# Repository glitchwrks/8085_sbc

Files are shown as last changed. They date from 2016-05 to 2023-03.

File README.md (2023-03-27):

# Glitch Works 8085 SBC

This repository contains the recovered EAGLE projects for the various PC boards designed as part of the Glitch Works 8085 SBC projects. These designs have been manufactured and tested and generally found to be functional; however, no warranty is made as to their fitness for any purpose. Please see the [LICENSE](https://github.com/glitchwrks/8085_sbc/blob/master/LICENSE) file for more information.

If you are interested in obtaining a bare circuit board, kit, or assembled board, please contact us through GitHub or [the Glitch Works contact form](https://services.theglitchworks.net/ng/messages/new). There's a chance we'll already have a bare board on hand, since later boards were ordered through [OSH Park](https://oshpark.com/) and resulted in three boards.

If you decide to produce any of these designs, or assemble a board from the provided schematics, please let us know through GitHub or [the Glitch Works contact form](https://services.theglitchworks.net/ng/messages/new).

### 8085 SBC rev 1

This is the original PC board produced from the "mess of wires" that started my exploration into the 8085 CPU! You can read more about the board's evolution and design [here](http://users.glitchwrks.com/~glitch/2010/09/02/8085-sbc). This board was meant to be the CPU board in a stack of boards, and contains 8K EPROM, 8K static RAM, an 8085, and associated clock generation and memory decode circuitry. You can flash a LED on the SOD pin with nothing more than this basic hardware.

### 8085 SBC rev 2

An extension of the rev 1 design, this board incorporates more RAM and ROM, mounting holes, and a few other features. Read about the board [here](http://users.glitchwrks.com/~glitch/2011/10/29/sbc-rev-2).

[AN0001 describes ROM jumpers](https://github.com/glitchwrks/8085_sbc/blob/master/8085_sbc_rev2/an0001_jumpers.txt) for socket IC3.

### I/O Board

This board contains a Zilog SCC (two channel USART) and Intel 8255 PPI to provide two serial ports and 24 bits of parallel I/O. It stacks on top of the 8085 SBC board, PC-104 style. Read about design and testing [here](http://users.glitchwrks.com/~glitch/2017/04/24/8085-io-board). I wrote a [ROM monitor](https://github.com/glitchwrks/gwmon-80) that works with this board. This was on display at [HOPE Number Nine](http://hope.net/) with the vintage computer guys.

There's an [ECO for old etches](https://github.com/glitchwrks/8085_sbc/blob/master/io_board/eco0007.txt) that is relevant if you got one of these boards from us before 2023. It corrects a routing error w.r.t. the 8255 PPI reset signal. See the linked writeup above for a picture documenting the fix.

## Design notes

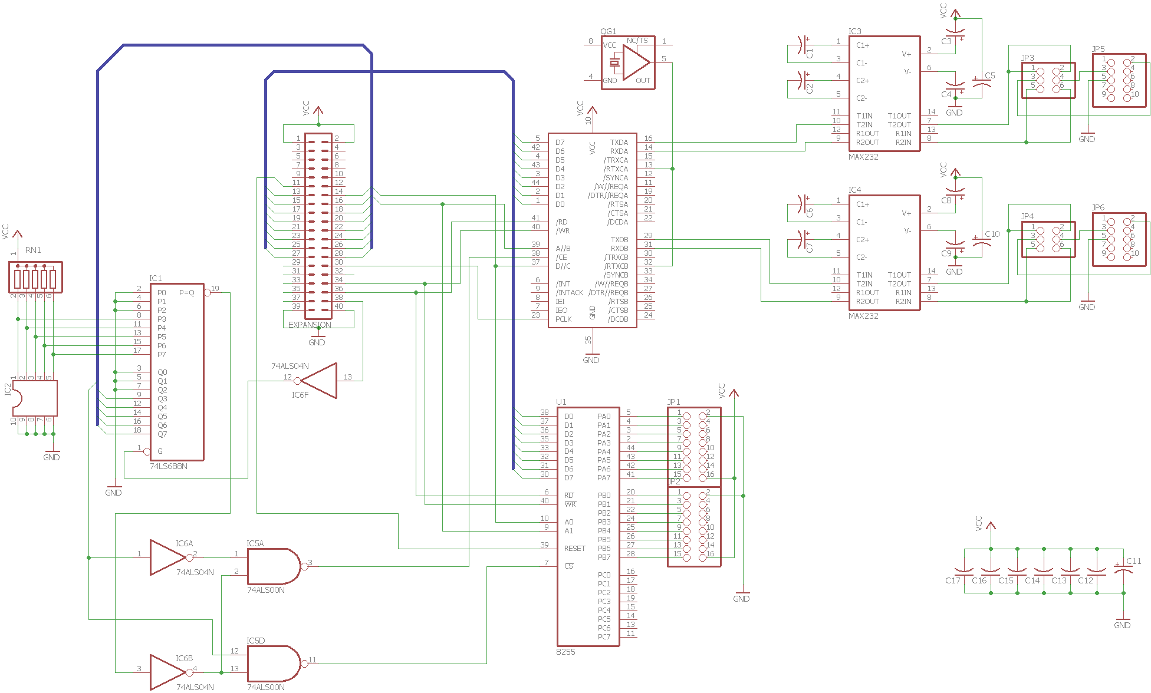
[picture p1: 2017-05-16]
io_board/schematic.png

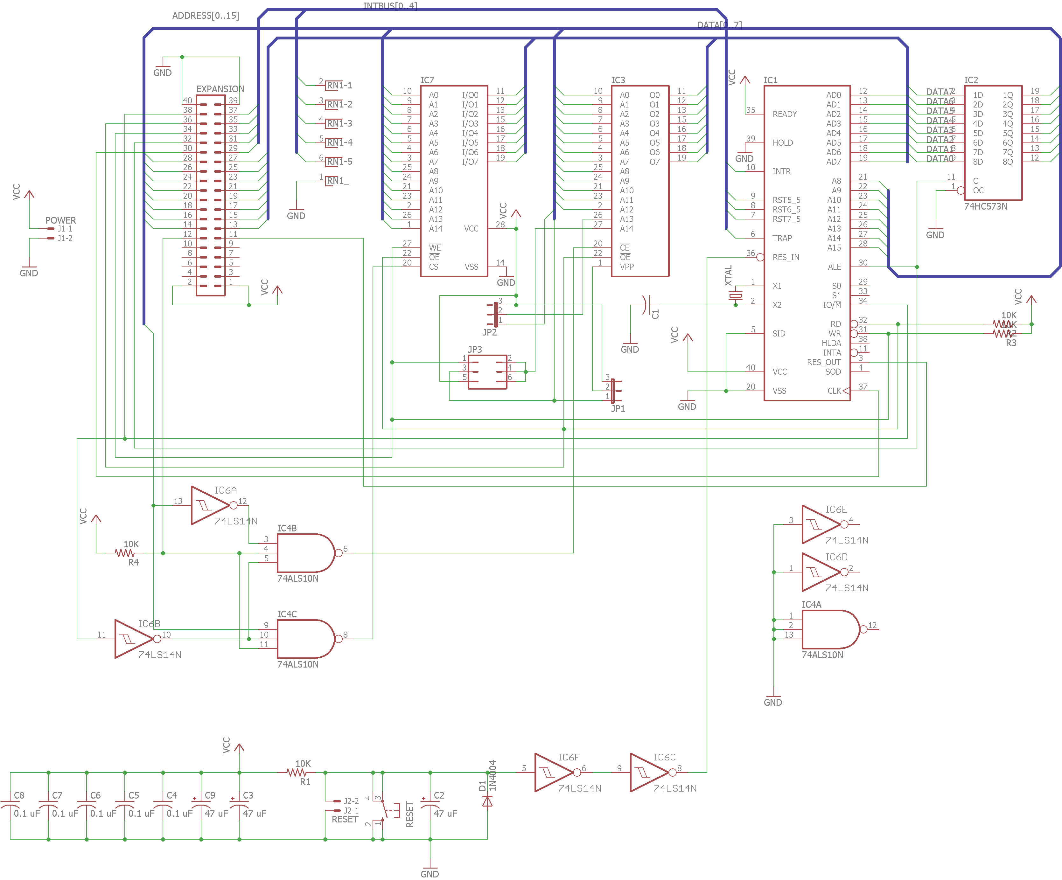
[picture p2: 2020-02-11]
8085_sbc_rev2/8085sbc_rev2.png

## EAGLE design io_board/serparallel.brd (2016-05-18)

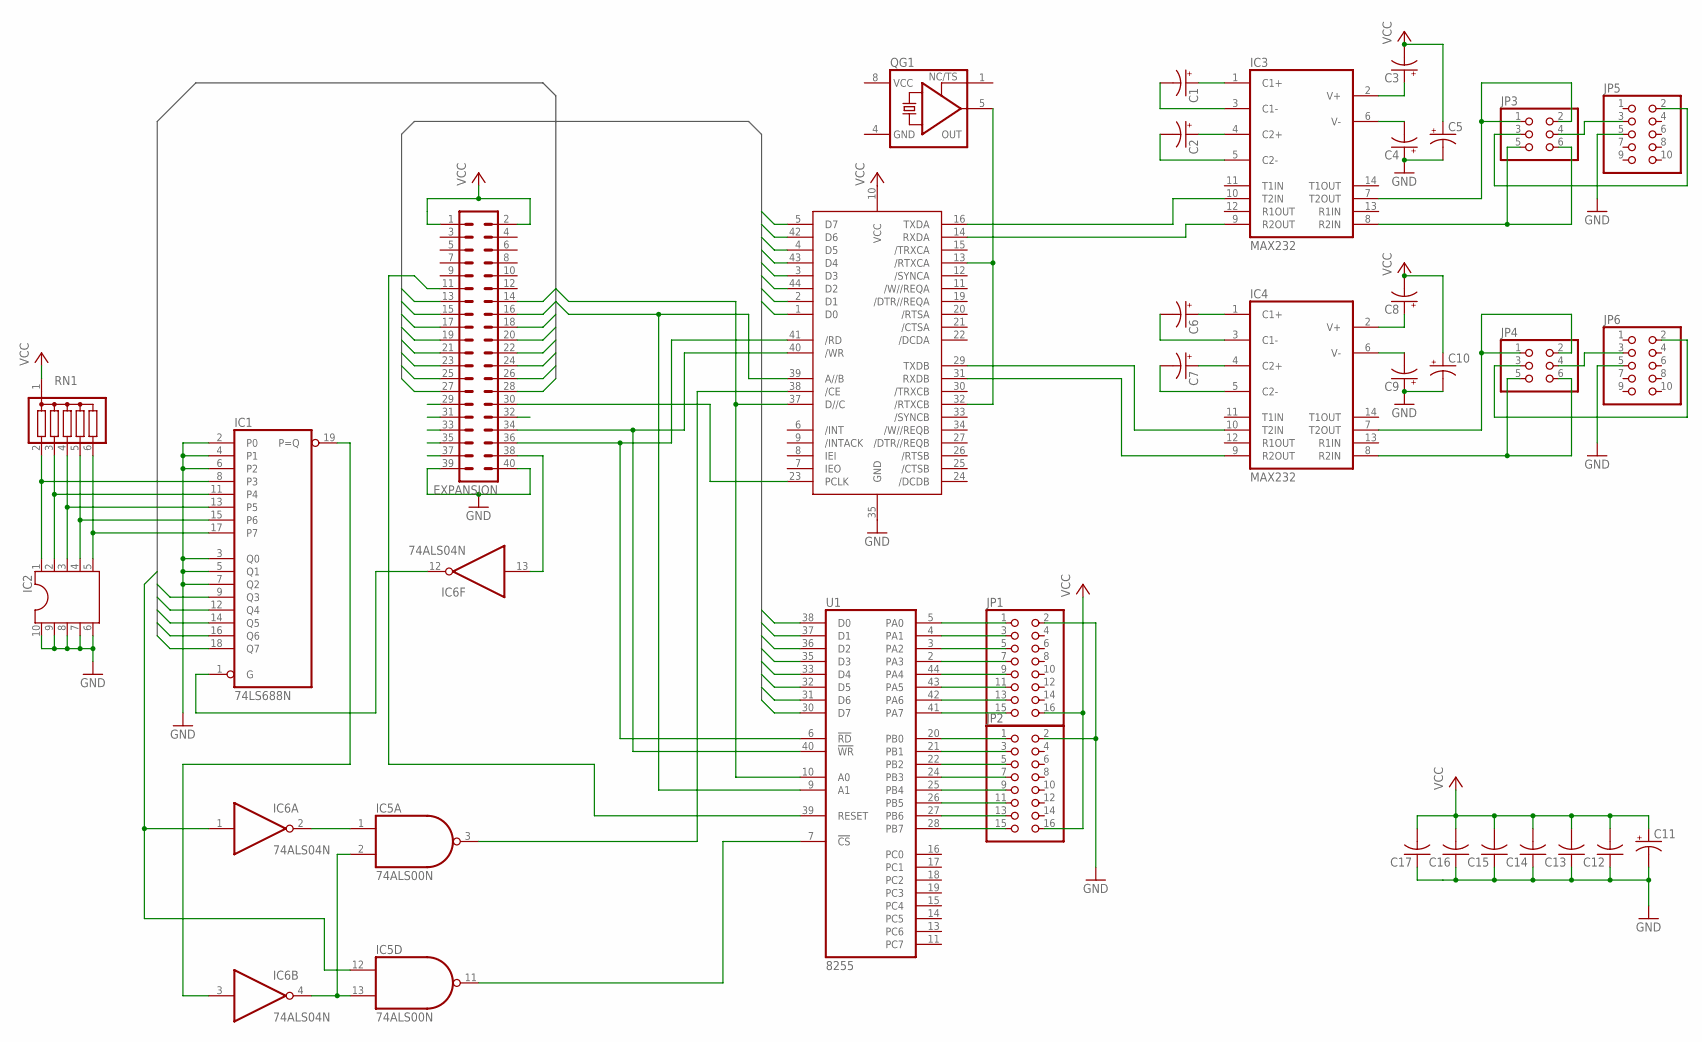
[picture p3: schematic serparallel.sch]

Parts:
C1, C2, C3, C4, C5, C6, C7, C8, C9, C10: CPOL-USE2,5-6E; E2,5-6E
C11: CPOL-USE15-6AXIAL; E15-6
C12, C13, C14, C15, C16, C17: C-US075-032X103; C075-032X103
EXPANSION: MA20-2W
IC1: 74LS688N; DIL20
IC2: DIL10
IC3, IC4: MAX232; DIL16
IC5: 74ALS00N; DIL14
IC6: 74ALS04N; DIL14
JP1, JP2: PINHD-2X8/90; 2X08/90
JP3, JP4: PINHD-2X3; 2X03
JP5, JP6: PINHD-2X5/90; 2X05/90
QG1: XO-8; DIL08S
RN1: G05R; SIL6
U1: 8255; S44
U2: Z8530; S44

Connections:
/RD: EXPANSION.36, U1.6 (!RD), U2.41 (/RD)
/WR: EXPANSION.34, U1.40 (!WR), U2.40 (/WR)
ADDRESS8: EXPANSION.14, U1.10 (A0), U2.37 (D//C)
ADDRESS9: EXPANSION.16, U1.9 (A1), U2.39 (A//B)
ADDRESS10: EXPANSION.18, IC5.12 (I0), IC6.1 (I)
ADDRESS11: EXPANSION.20, IC1.9 (Q3)
ADDRESS12: EXPANSION.22, IC1.12 (Q4)
ADDRESS13: EXPANSION.24, IC1.14 (Q5)
ADDRESS14: EXPANSION.26, IC1.16 (Q6)
ADDRESS15: EXPANSION.28, IC1.18 (Q7)
ALE: EXPANSION.32
CLKOUT: EXPANSION.30, U2.23 (PCLK)
DATA0: EXPANSION.27, U1.38 (D0), U2.1 (D0)
DATA1: EXPANSION.25, U1.37 (D1), U2.2 (D1)
DATA2: EXPANSION.23, U1.36 (D2), U2.44 (D2)
DATA3: EXPANSION.21, U1.35 (D3), U2.3 (D3)
DATA4: EXPANSION.19, U1.33 (D4), U2.43 (D4)
DATA5: EXPANSION.17, U1.32 (D5), U2.4 (D5)
DATA6: EXPANSION.15, U1.31 (D6), U2.42 (D6)
DATA7: EXPANSION.13, U1.30 (D7), U2.5 (D7)
GND: C4.+, C5.-, C9.+, C10.-, C11.-, C12.1, C13.1, C14.1, C15.1, C16.1, C17.1, EXPANSION.39, EXPANSION.40, IC1.2 (P0), IC1.3 (Q0), IC1.4 (P1), IC1.5 (Q1), IC1.6 (P2), IC1.7 (Q2), IC1.10 (GND), IC2.6, IC2.7, IC2.8, IC2.9, IC2.10, IC3.15 (GND), IC4.15 (GND), IC5.7 (GND), IC6.7 (GND), JP1.2, JP2.2, JP5.5, JP6.5, QG1.4 (GND), U1.8 (GND), U2.35 (GND)
INTBUS0: EXPANSION.37
INTBUS1: EXPANSION.35
INTBUS2: EXPANSION.33
INTBUS3: EXPANSION.31
INTBUS4: EXPANSION.29
IO/M: EXPANSION.38, IC6.13 (I)
unnamed: IC1.8 (P3), IC2.1, RN1.2
unnamed: IC1.11 (P4), IC2.2, RN1.3
unnamed: IC1.13 (P5), IC2.3, RN1.4
unnamed: IC1.15 (P6), IC2.4, RN1.5
unnamed: IC1.17 (P7), IC2.5, RN1.6
unnamed: IC5.1 (I0), IC6.2 (O)
unnamed: IC5.2 (I1), IC5.13 (I1), IC6.4 (O)
unnamed: C1.+, IC3.1 (C1+)
unnamed: C1.-, IC3.3 (C1-)
unnamed: C2.+, IC3.4 (C2+)
unnamed: C2.-, IC3.5 (C2-)
unnamed: C3.+, IC3.2 (V+)
unnamed: C4.-, IC3.6 (V-)
unnamed: C6.+, IC4.1 (C1+)
unnamed: IC5.3 (O), U2.38 (/CE)
unnamed: C6.-, IC4.3 (C1-)
unnamed: C7.+, IC4.4 (C2+)
unnamed: C7.-, IC4.5 (C2-)
unnamed: C8.+, IC4.2 (V+)
unnamed: C9.-, IC4.6 (V-)
unnamed: QG1.5 (OUT), U2.13 (/RTXCA), U2.32 (/RTXCB)
unnamed: IC3.10 (T2IN), U2.16 (TXDA)
unnamed: IC3.9 (R2OUT), U2.14 (RXDA)
unnamed: JP3.4, JP5.3
unnamed: JP3.3, JP5.2
unnamed: IC3.8 (R2IN), JP3.5, JP3.6
unnamed: JP1.1, U1.5 (PA0)
unnamed: IC3.7 (T2OUT), JP3.1, JP3.2
unnamed: JP1.3, U1.4 (PA1)
unnamed: JP1.5, U1.3 (PA2)
unnamed: JP1.7, U1.2 (PA3)
unnamed: JP1.9, U1.44 (PA4)
unnamed: JP1.11, U1.43 (PA5)
unnamed: JP1.13, U1.42 (PA6)
unnamed: JP1.15, U1.41 (PA7)
unnamed: JP2.1, U1.20 (PB0)
unnamed: JP2.3, U1.21 (PB1)
unnamed: JP2.5, U1.22 (PB2)
unnamed: JP2.7, U1.24 (PB3)
unnamed: JP2.9, U1.25 (PB4)
unnamed: JP2.11, U1.26 (PB5)
unnamed: JP2.13, U1.27 (PB6)
unnamed: JP2.15, U1.28 (PB7)
unnamed: IC5.11 (O), U1.7 (!CS)
unnamed: IC1.19 (P=Q), IC6.3 (I)
unnamed: IC1.1 (G), IC6.12 (O)
unnamed: JP4.4, JP6.3
unnamed: JP4.3, JP6.2
unnamed: IC4.7 (T2OUT), JP4.1, JP4.2
unnamed: IC4.8 (R2IN), JP4.5, JP4.6
unnamed: IC4.10 (T2IN), U2.29 (TXDB)
unnamed: IC4.9 (R2OUT), U2.31 (RXDB)
RESOUT: EXPANSION.11, U1.39 (RESET)
VCC: C3.-, C5.+, C8.-, C10.+, C11.+, C12.2, C13.2, C14.2, C15.2, C16.2, C17.2, EXPANSION.1, EXPANSION.2, IC1.20 (VCC), IC3.16 (VCC), IC4.16 (VCC), IC5.14 (VCC), IC6.14 (VCC), JP1.16, JP2.16, QG1.8 (VCC), RN1.1, U1.29 (VCC), U2.10 (VCC)

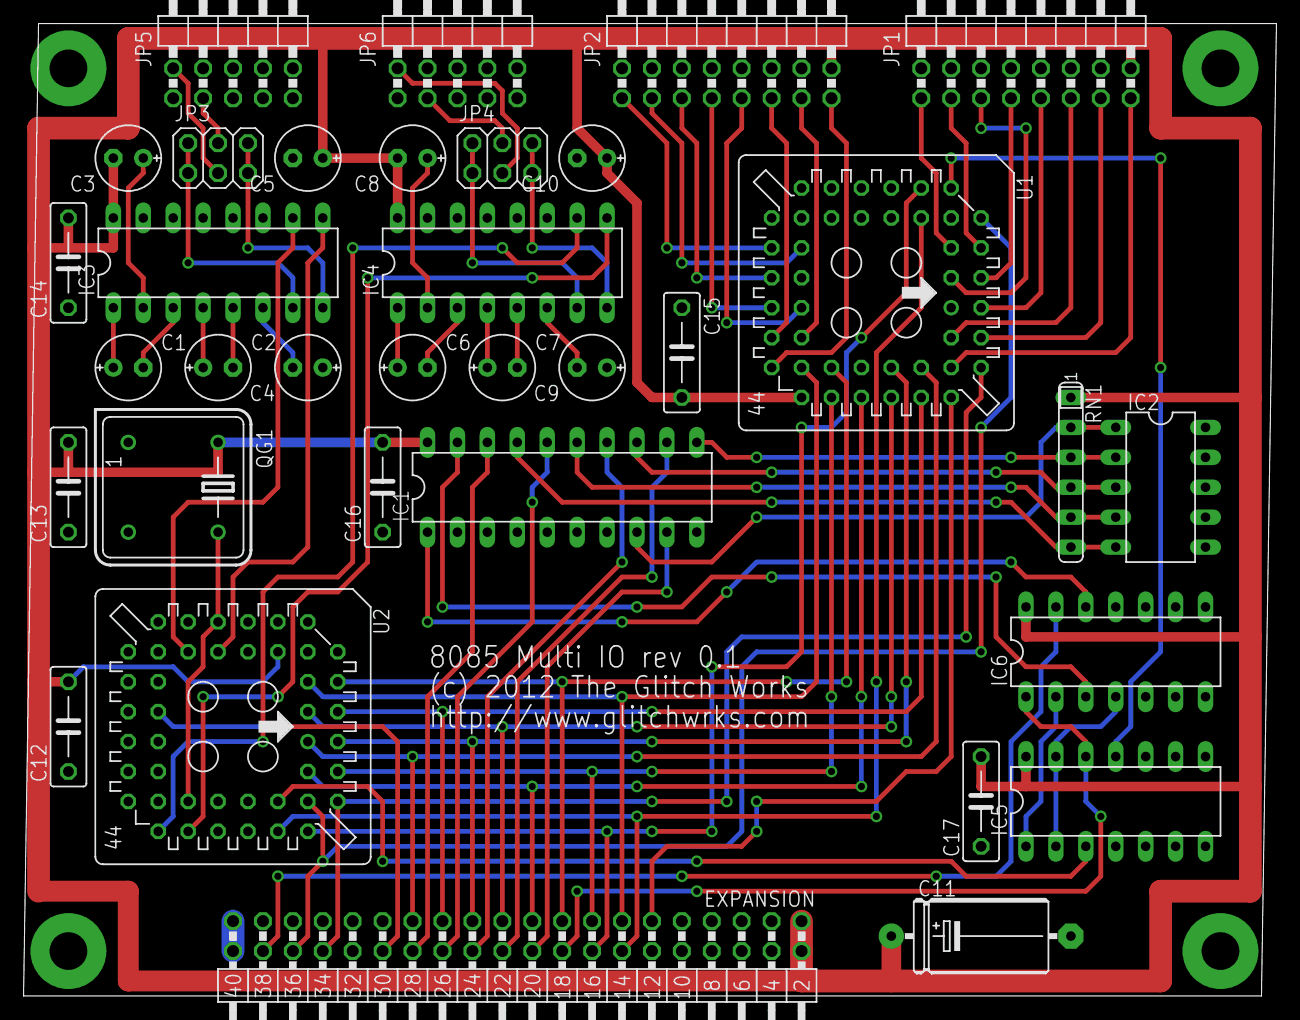
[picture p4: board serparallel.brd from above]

Board: 2 copper layers, 106.3 x 82.5 mm, 34 parts (0 on the bottom side), 75 nets.

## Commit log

2017-05-16 Adding Multi-IO PNG schematic
2020-02-11 Adding PNG schematics for 8085 SBC rev 1,2

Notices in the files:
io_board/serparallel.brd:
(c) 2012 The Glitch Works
